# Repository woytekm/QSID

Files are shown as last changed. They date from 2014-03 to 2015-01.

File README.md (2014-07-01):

Q-SID: a 4-voice polyphonic MIDI synth based on four SID 8580 chips 

Features:

 Hardware/OS: 

 Q-SID will have a modular construction: every functional block of the device will have it's own PCB:
  - CPU board - Raspberry Pi, or other SoC board with two I2C busses, UART, at least 16 GPIO's, USB and ethernet
  - four voice boards, each with one 8580 SID chip
  - MIDI interface board
  - DSP/mixer board 
  - front controls board with rotary encoders and buttons for sound parameters control 
  - front display board 
  - I2C voltage level converter for voice boards
  - power supply with +9V, +5V switched for CPU, +5V linear for voice boards, +3.3V

 Q-SID will have an operating system in form of single multithreaded process of Linux OS, running on custom Raspbian image scaled down to
 stripped Linux kernel, Q-SID OS process, and prefferably nothing more (to spare CPU cycles and other resources).

 Synthetizer features:

  - 4 SID engines with full SID features
  - polyphonic mode with 4 voice polyphony
  - performance mode with keyboard/voice/patch split 
  - arpeggiator (not sure about exact parameters yet)
  - 2 software LFO's modulating filter cutoff/resonance, PWM, oscillator detune, and other parameters
  - onboard sound effects via internal DSP
  - MIDI in/out with programmable MIDI channel
  - embedded .sid chiptune player

====

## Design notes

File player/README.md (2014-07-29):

This directory contains complete, patched sources of sidplay and libsidplay2.
HardSID builder code was modified to use QSID voice board instead of HardSID card. 
Use: --hardsid --addr <board address> to play .sid song on a QSID voice board.

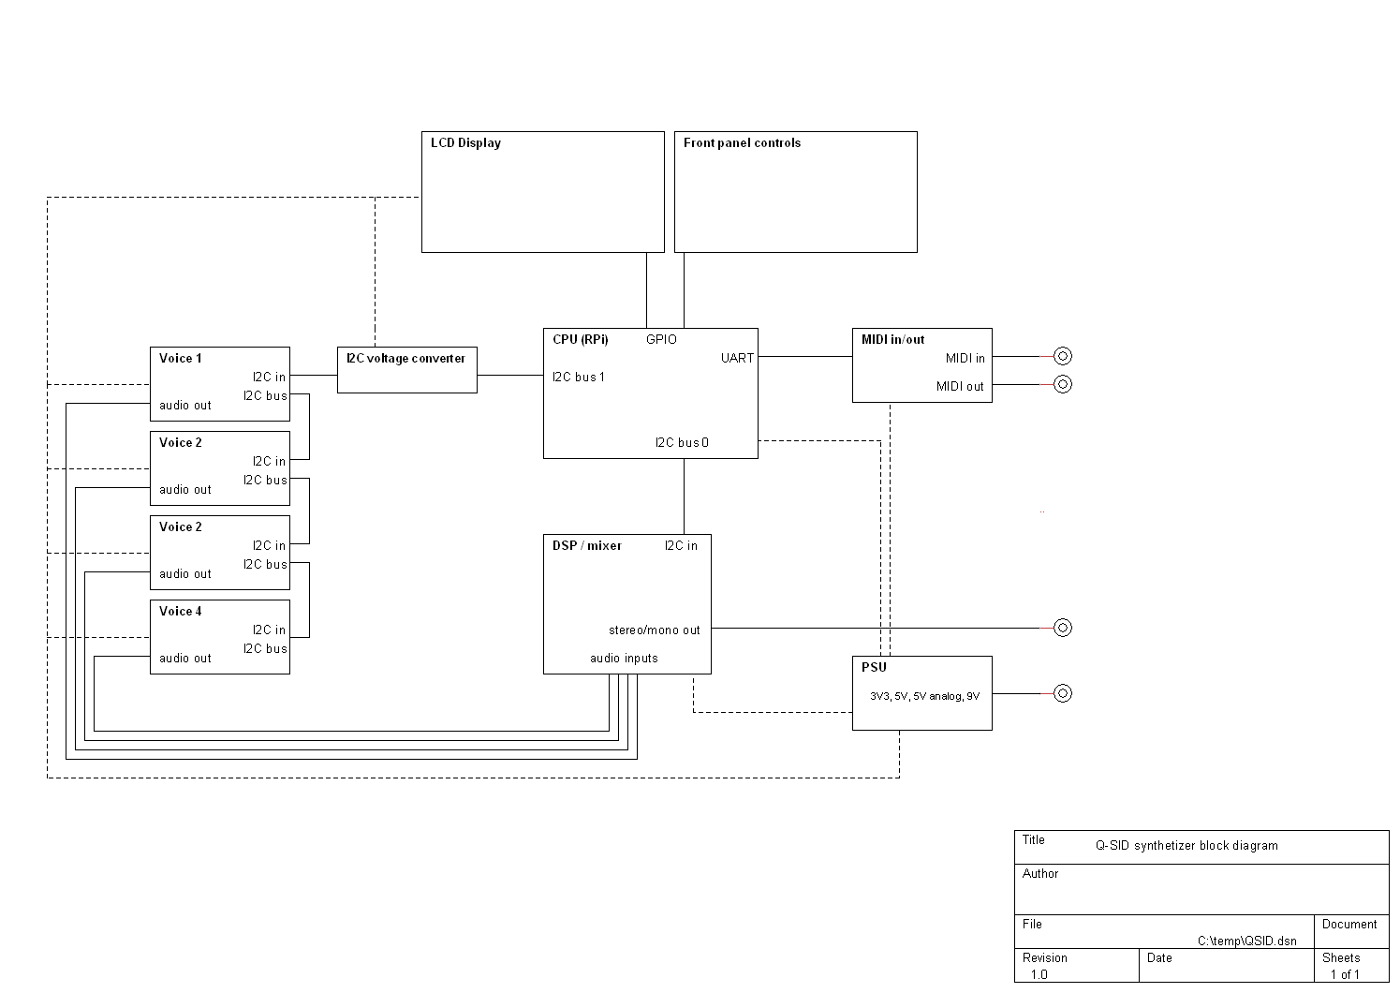
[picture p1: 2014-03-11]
hardware/Q-SID_block_diagram.png

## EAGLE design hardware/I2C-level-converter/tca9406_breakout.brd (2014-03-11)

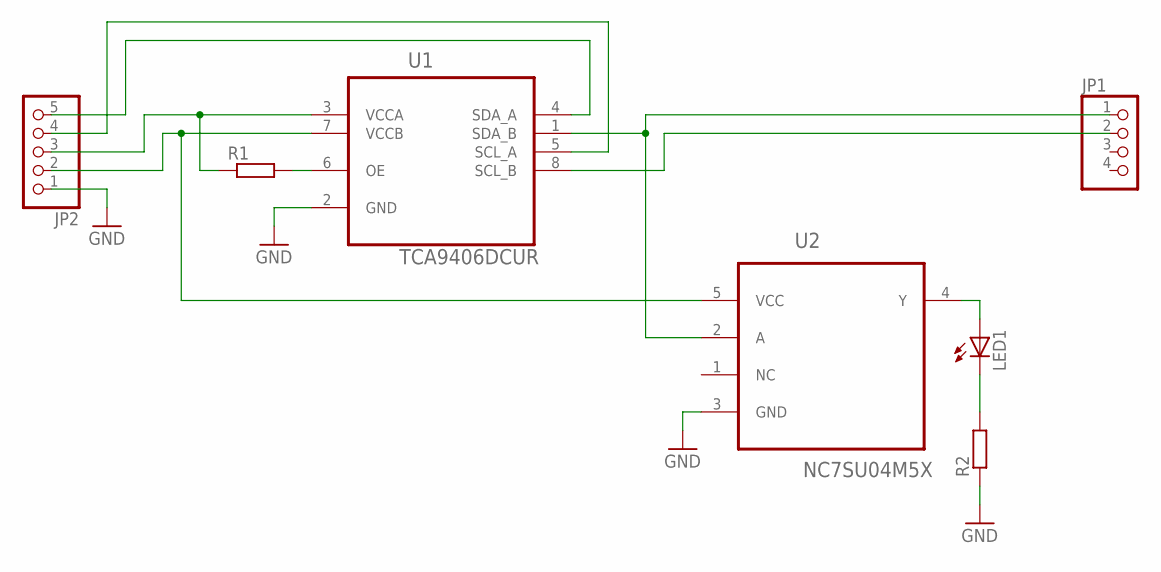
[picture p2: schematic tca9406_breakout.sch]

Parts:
JP1: PINHD-1X4; 1X04
JP2: PINHD-1X5; 1X05
LED1: LEDSML1206; SML1206
R1, R2: R-EU_M1406; M1406
U1: TCA9406DCUR; SOP50P310X90-8N
U2: NC7SU04M5X; SOT95P280X145-5N

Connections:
GND: JP2.1, R2.1, U1.2 (GND), U2.3 (GND)
unnamed: JP1.2, U1.8 (SCL_B)
unnamed: JP1.1, U1.1 (SDA_B), U2.2 (A)
unnamed: JP2.5, U1.4 (SDA_A)
unnamed: JP2.4, U1.5 (SCL_A)
unnamed: JP2.3, R1.1, U1.3 (VCCA)
unnamed: JP2.2, U1.7 (VCCB), U2.5 (VCC)
unnamed: LED1.A, U2.4 (Y)
unnamed: R1.2, U1.6 (OE)
unnamed: LED1.C, R2.2

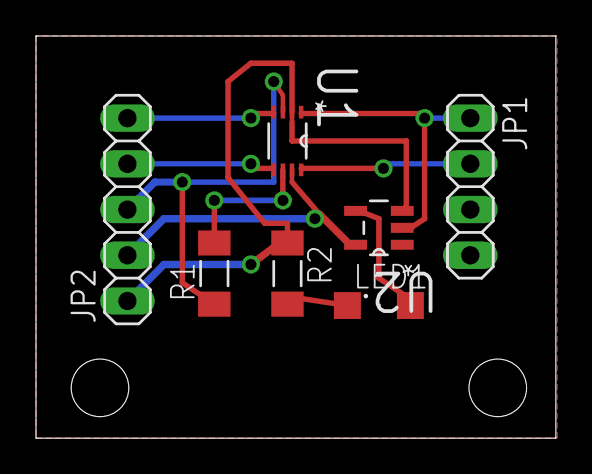
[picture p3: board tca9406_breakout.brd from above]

Board: 2 copper layers, 28.9 x 22.3 mm, 7 parts (0 on the bottom side), 10 nets.

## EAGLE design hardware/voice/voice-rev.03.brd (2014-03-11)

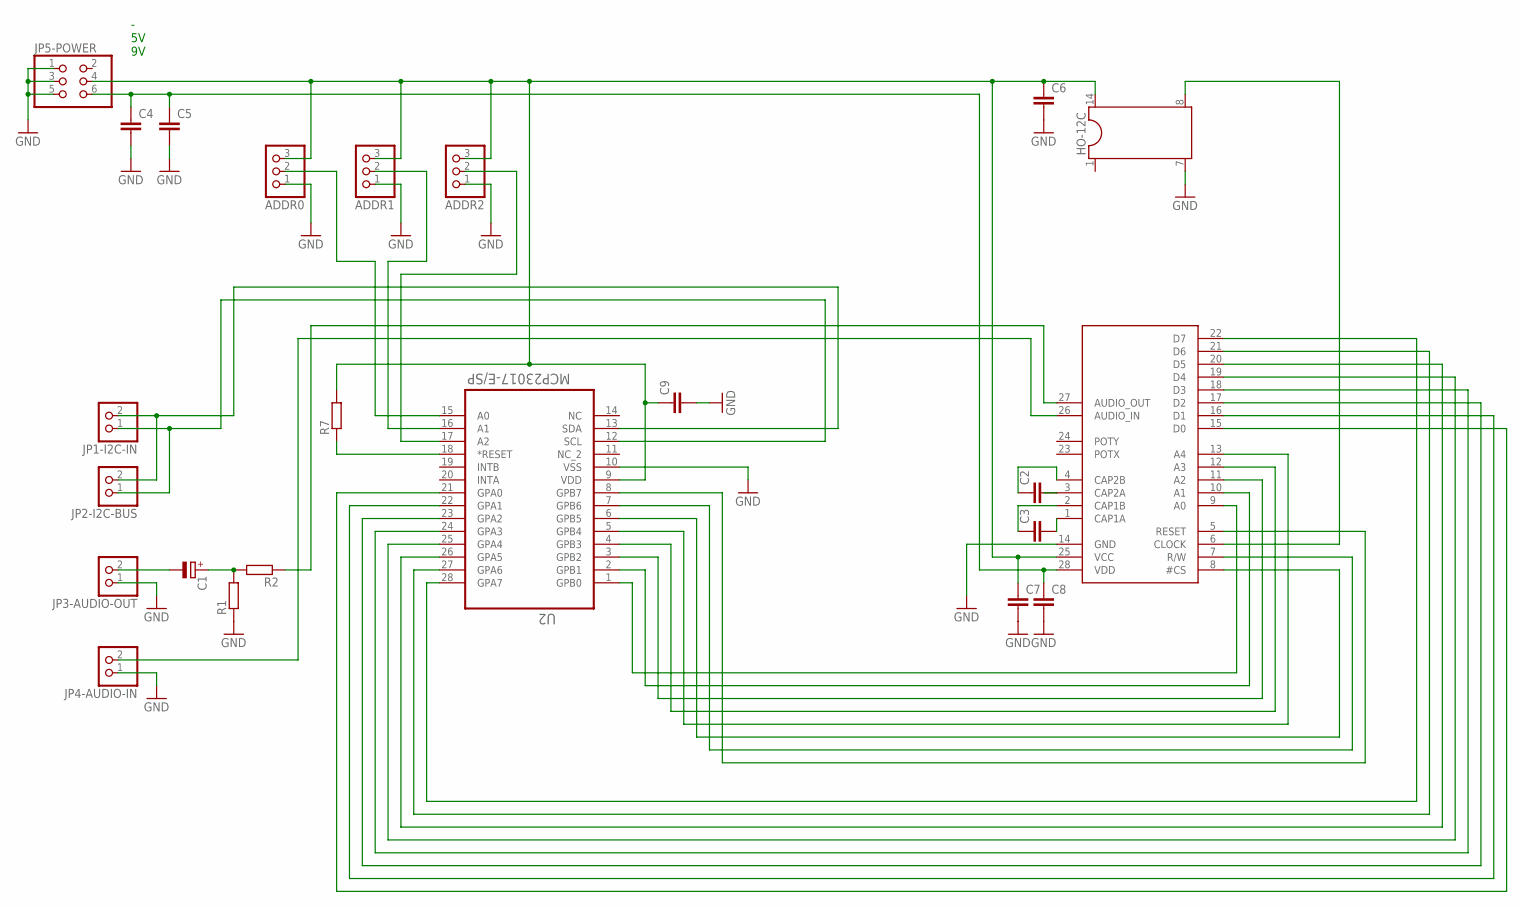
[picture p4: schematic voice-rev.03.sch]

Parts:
ADDR0, ADDR1, ADDR2: PINHD-1X3; 1X03
C1: CPOL-EUE2.5-5; E2,5-5
C2, C3: C5/2.5; C5B2.5
C4, C5, C6, C7, C8, C9: C-EU050-024X044; C050-024X044
HO-12C: DIL14/4
JP1-I2C-IN, JP2-I2C-BUS, JP3-AUDIO-OUT, JP4-AUDIO-IN: PINHD-1X2; 1X02
JP5-POWER: PINHD-2X3; 2X03
R1, R2, R7: R-EU_0207/5V; 0207/5V
U2: MCP23017-E/SP; DIP254P762X406-28P
U$1: 6581; DIL28-6

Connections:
GND: ADDR0.1, ADDR1.1, ADDR2.1, C4.2, C5.2, C6.2, C7.2, C8.2, C9.2, HO-12C.7 (8), JP3-AUDIO-OUT.1, JP4-AUDIO-IN.1, JP5-POWER.1, JP5-POWER.3, JP5-POWER.5, R1.1, U2.10 (VSS), U$1.14 (GND)
unnamed: U2.1 (GPB0), U$1.9 (A0)
unnamed: U2.2 (GPB1), U$1.10 (A1)
unnamed: U2.3 (GPB2), U$1.11 (A2)
unnamed: U2.4 (GPB3), U$1.12 (A3)
unnamed: U2.5 (GPB4), U$1.13 (A4)
unnamed: U2.6 (GPB5), U$1.8 (#CS)
unnamed: U2.7 (GPB6), U$1.7 (R/W)
unnamed: U2.8 (GPB7), U$1.5 (RESET)
unnamed: U2.28 (GPA7), U$1.22 (D7)
unnamed: U2.27 (GPA6), U$1.21 (D6)
unnamed: U2.26 (GPA5), U$1.20 (D5)
unnamed: U2.25 (GPA4), U$1.19 (D4)
unnamed: U2.24 (GPA3), U$1.18 (D3)
unnamed: U2.23 (GPA2), U$1.17 (D2)
unnamed: U2.22 (GPA1), U$1.16 (D1)
unnamed: U2.21 (GPA0), U$1.15 (D0)
unnamed: HO-12C.8 (9), U$1.6 (CLOCK)
unnamed: C1.+, R1.2, R2.2
unnamed: C4.1, C5.1, C8.1, JP5-POWER.6, U$1.28 (VDD)
unnamed: R2.1, U$1.27 (AUDIO_OUT)
unnamed: JP4-AUDIO-IN.2, U$1.26 (AUDIO_IN)
unnamed: JP1-I2C-IN.2, JP2-I2C-BUS.2, U2.13 (SDA)
unnamed: JP1-I2C-IN.1, JP2-I2C-BUS.1, U2.12 (SCL)
unnamed: C1.-, JP3-AUDIO-OUT.2
unnamed: C3.2, U$1.1 (CAP1A)
unnamed: C3.1, U$1.2 (CAP1B)
unnamed: C2.2, U$1.3 (CAP2A)
unnamed: C2.1, U$1.4 (CAP2B)
unnamed: ADDR0.2, U2.15 (A0)
unnamed: ADDR1.2, U2.16 (A1)
unnamed: ADDR2.2, U2.17 (A2)
unnamed: R7.1, U2.18 (*RESET)
unnamed: ADDR0.3, ADDR1.3, ADDR2.3, C6.1, C7.1, C9.1, HO-12C.14 (16), JP5-POWER.4, R7.2, U2.9 (VDD), U$1.25 (VCC)

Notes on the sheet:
- 5V 9V

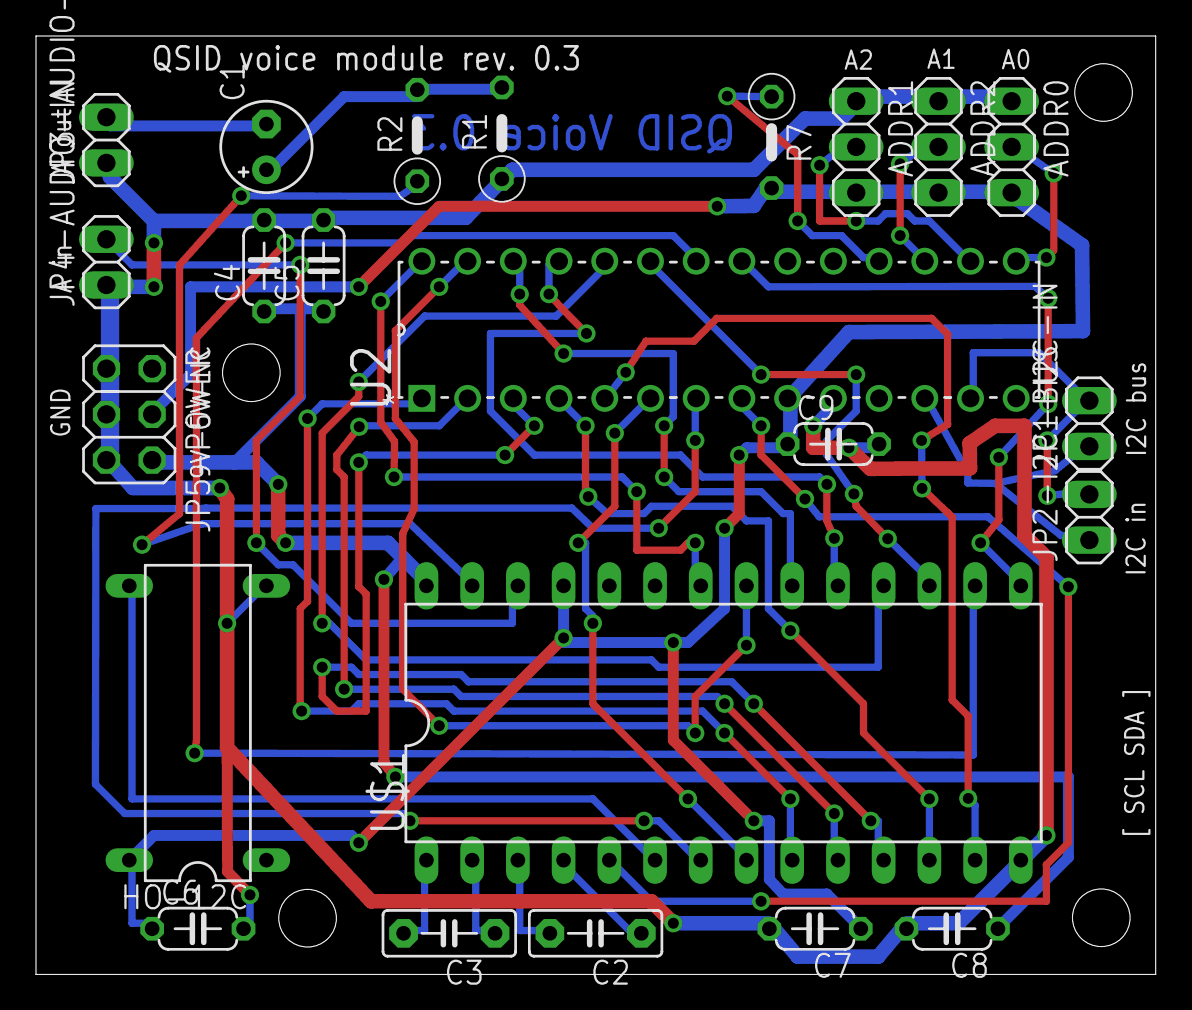
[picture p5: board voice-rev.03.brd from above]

Board: 2 copper layers, 62.2 x 52.1 mm, 23 parts (0 on the bottom side), 34 nets.

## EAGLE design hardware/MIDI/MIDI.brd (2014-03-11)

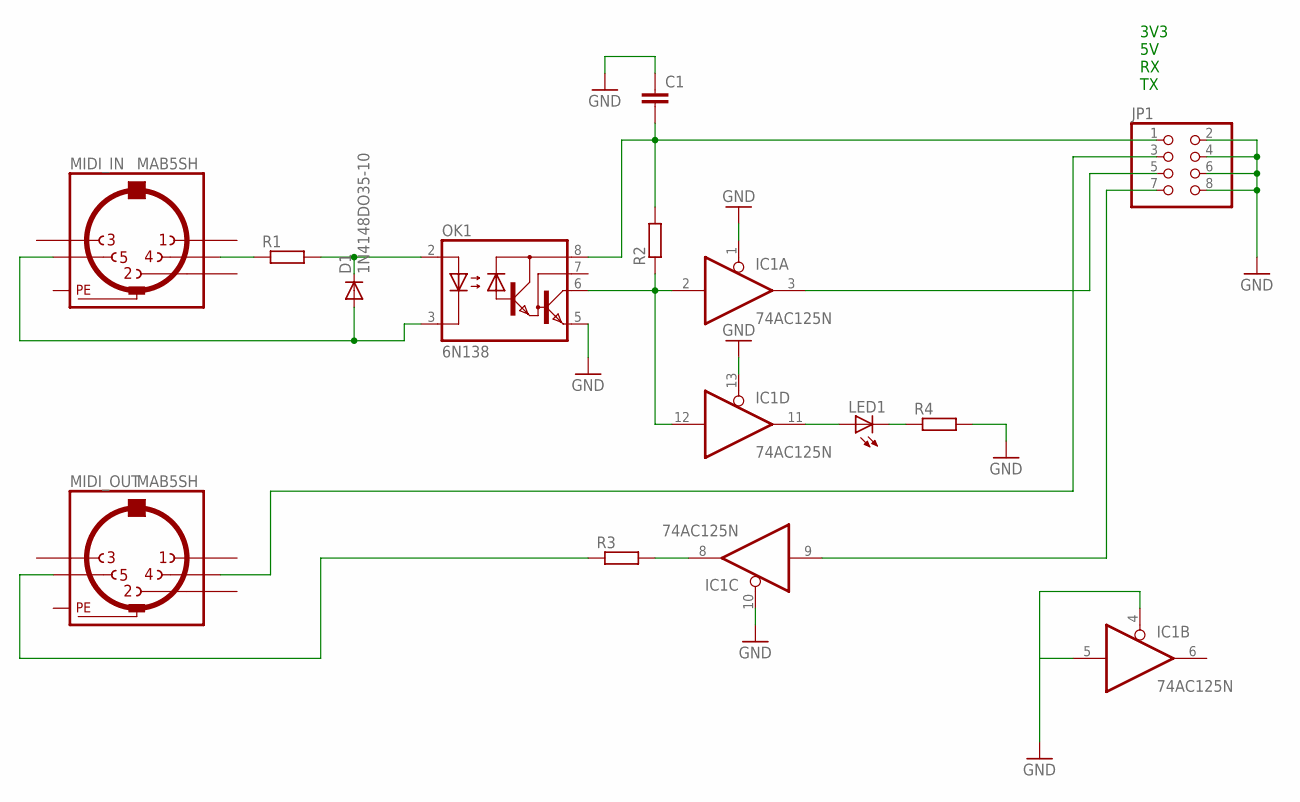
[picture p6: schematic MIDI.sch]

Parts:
C1: C-EU050-024X044; C050-024X044
D1: 1N4148DO35-10; DO35-10
IC1: 74AC125N; DIL14
JP1: PINHD-2X4; 2X04
LED1: LED3MM
MIDI_IN: MAB5SH
MIDI_OUT: MAB5SH
OK1: 6N138; DIL08
R1, R2, R3, R4: R-EU_0207/5V; 0207/5V

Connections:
GND: C1.1, IC1.1 (OE), IC1.4 (OE), IC1.5 (I), IC1.7 (GND), IC1.10 (OE), IC1.13 (OE), JP1.2, JP1.4, JP1.6, JP1.8, MIDI_IN.PE, MIDI_IN.PE@ (PE), MIDI_OUT.PE, MIDI_OUT.PE@ (PE), OK1.5 (GND), R4.2
unnamed: MIDI_IN.4, R1.1
unnamed: D1.C, OK1.2 (A), R1.2
unnamed: D1.A, MIDI_IN.5, OK1.3 (C)
unnamed: IC1.8 (O), R3.2
unnamed: IC1.2 (I), IC1.12 (I), OK1.6 (VO), R2.1
unnamed: IC1.3 (O), JP1.5
unnamed: MIDI_OUT.5, R3.1
unnamed: JP1.3, MIDI_OUT.4
unnamed: IC1.9 (I), JP1.7
unnamed: IC1.11 (O), LED1.A
unnamed: LED1.K (C), R4.1
VCC: C1.2, IC1.14 (VCC), JP1.1, OK1.8 (VCC), R2.2

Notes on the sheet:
3V3 5V RX TX

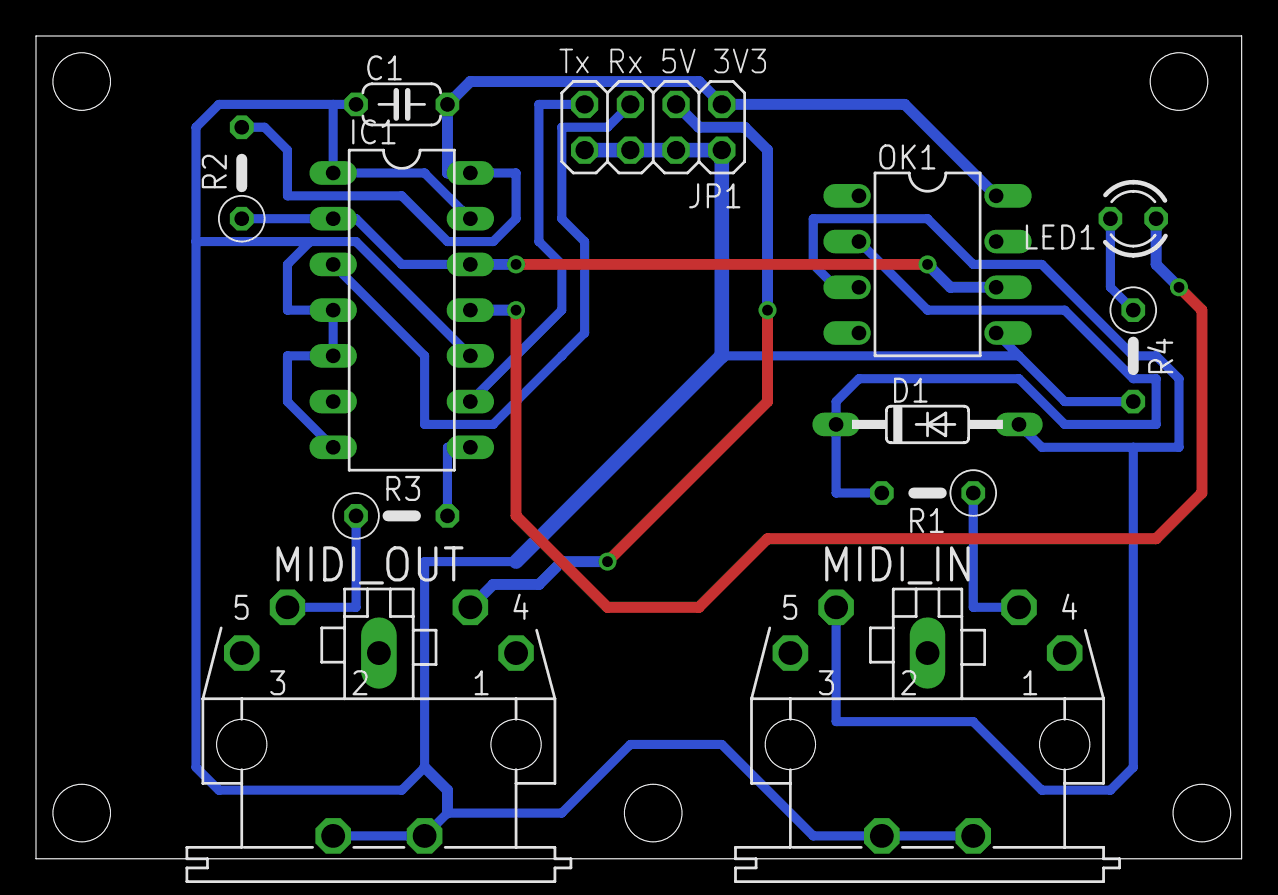
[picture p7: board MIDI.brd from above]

Board: 2 copper layers, 67.0 x 45.7 mm, 12 parts (0 on the bottom side), 13 nets.

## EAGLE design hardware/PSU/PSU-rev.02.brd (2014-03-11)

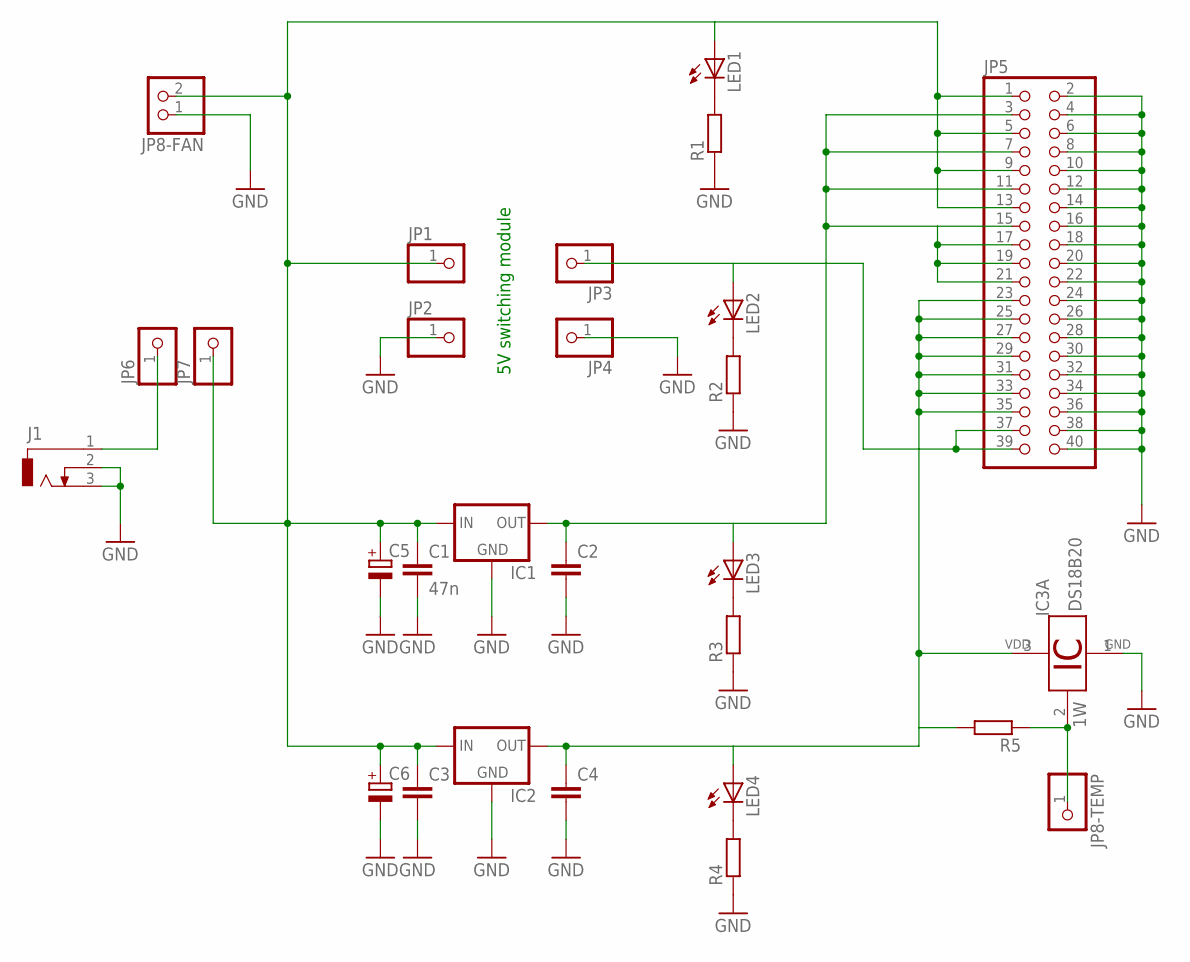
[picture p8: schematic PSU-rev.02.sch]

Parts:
C1: 47n; C050-024X044
C2, C3, C4: C-EU050-024X044; C050-024X044
C5, C6: CPOL-EUE3.5-8; E3,5-8
IC1, IC2: 78XXL
IC3: DS18B20; TO92-
J1: DCJ0303
JP1, JP2, JP3, JP4, JP6, JP7, JP8-TEMP: PINHD-1X1; 1X01
JP5: PINHD-2X20; 2X20
JP8-FAN: PINHD-1X2; 1X02
LED1, LED2, LED3, LED4: LEDSML1206; SML1206
R1, R2, R3, R4, R5: R-EU_R1206; R1206

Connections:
GND: C1.2, C2.2, C3.2, C4.2, C5.-, C6.-, IC1.GND, IC2.GND, IC3.1 (GND), J1.2, J1.3, JP2.1, JP4.1, JP5.2, JP5.4, JP5.6, JP5.8, JP5.10, JP5.12, JP5.14, JP5.16, JP5.18, JP5.20, JP5.22, JP5.24, JP5.26, JP5.28, JP5.30, JP5.32, JP5.34, JP5.36, JP5.38, JP5.40, JP8-FAN.1, R1.1, R2.1, R3.1, R4.1
unnamed: C1.1, C3.1, C5.+, C6.+, IC1.IN, IC2.IN, JP1.1, JP5.1, JP5.5, JP5.9, JP5.13, JP7.1, JP8-FAN.2, LED1.A
unnamed: C2.1, IC1.OUT, JP5.3, JP5.7, JP5.11, JP5.15, JP5.17, JP5.19, JP5.21, LED3.A
unnamed: C4.1, IC2.OUT, IC3.3 (VDD), JP5.23, JP5.25, JP5.27, JP5.29, JP5.31, JP5.33, JP5.35, LED4.A, R5.2
unnamed: JP3.1, JP5.37, JP5.39, LED2.A
unnamed: J1.1, JP6.1
unnamed: IC3.2 (1W), JP8-TEMP.1, R5.1
unnamed: LED1.C, R1.2
unnamed: LED2.C, R2.2
unnamed: LED3.C, R3.2
unnamed: LED4.C, R4.2

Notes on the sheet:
5V switching module

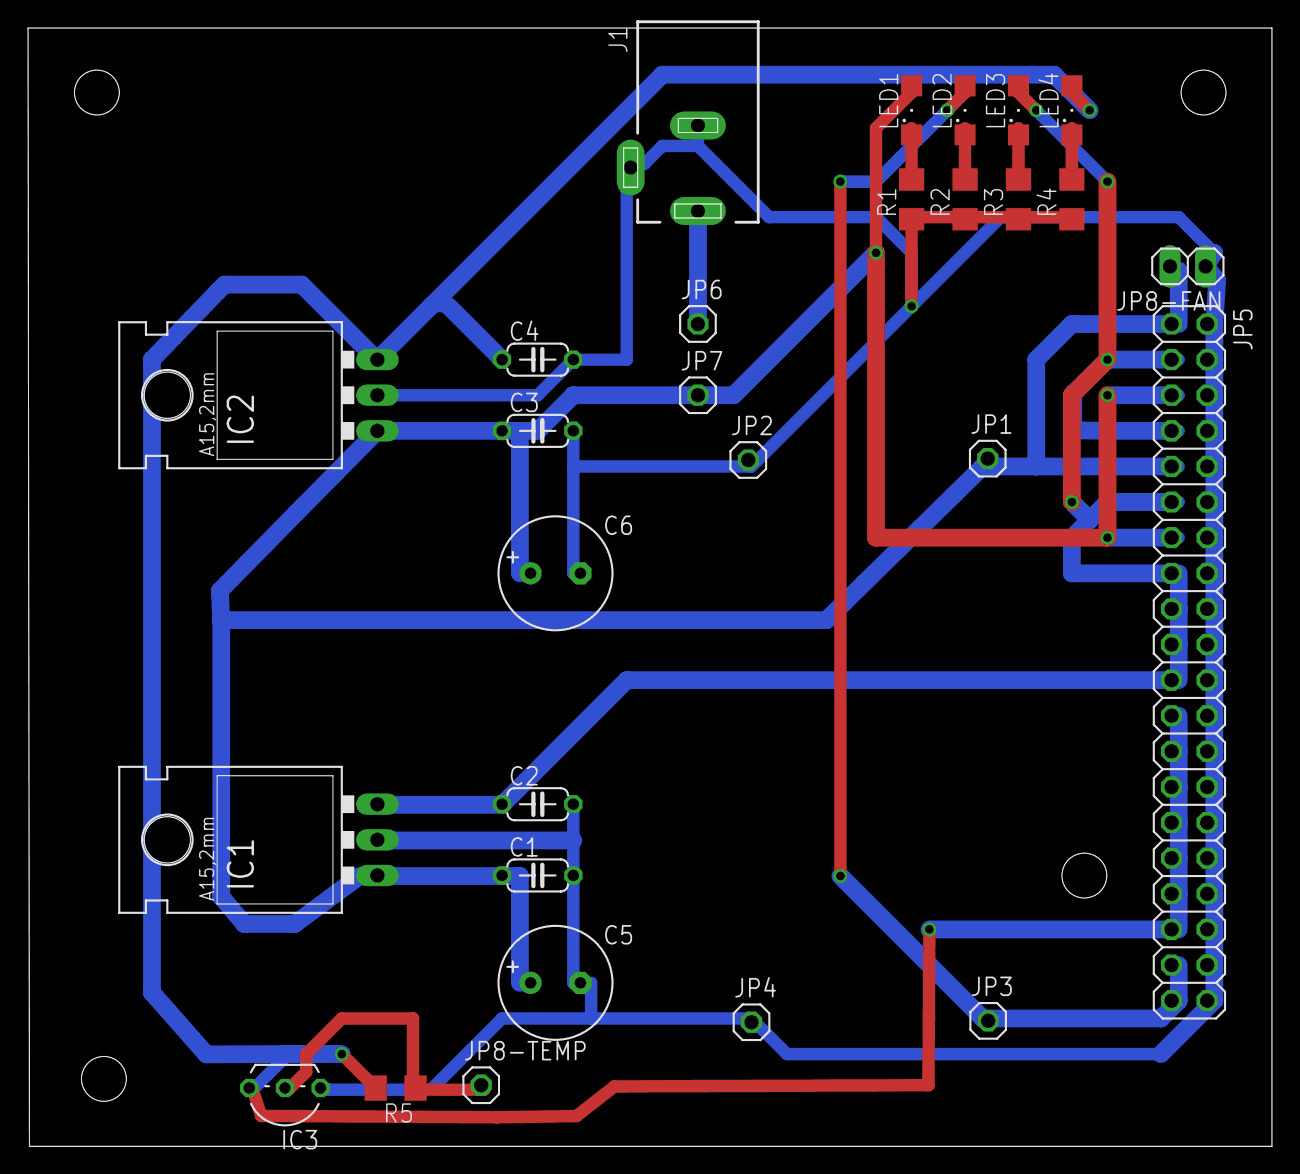
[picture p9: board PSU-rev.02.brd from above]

Board: 2 copper layers, 88.7 x 79.8 mm, 28 parts (0 on the bottom side), 11 nets.

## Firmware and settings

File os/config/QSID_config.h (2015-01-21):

/*

 Q-SID OS

 system configuration

*/

#define QSID_OS_VERSION_MAJOR 0
#define QSID_OS_VERSION_MINOR 1 

#ifdef I2C_BCM2835

#define I2C_VOICE_BUS 1
#define I2C_AUX_BUS 0
#define QSID_I2C_CLOCK 800000

#else

#define I2C_VOICE_BUS "/dev/i2c-1"
#define I2C_AUX_BUS   "/dev/i2c-0"

#endif

#define QSID_DEFAULT_THREAD_STACK_SIZE 1024000

#define QSID_DEBUG 1
#define QSID_DEBUG_LEVEL 3

#define QSID_OS_SID_REMOTE_CONTROL_PORT 6677
#define QSID_OS_MIDI_UDP_PORT 6678

#define DISCARD_DUPLICATE_NOTES 1
#define USE_SILENCERS 1

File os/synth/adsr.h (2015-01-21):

/* flags indicating events */
 
sig_atomic_t G_V_ADSR_stop[9];

sig_atomic_t G_V_ADSR_release_start[9];

/* signal handler arrays */

void (*G_ADSR_release_SH[9])(int);
void (*G_ADSR_stop_SH[9])(int);

/* modulation steps & intervals */

static const uint16_t G_ADSR_attack_steps[16] = {5,10,20,25,25,25,25,25,25,25,25,25,50,50,50,50};
static const uint32_t G_ADSR_attack_intervals[16] = {400,800,800,960,1520,2240,2720,3200,4000,10000,20000,
                                                     32000,20000,60000,100000,160000};
static const uint16_t G_ADSR_attack_step_size[16] = {409,204,102,81,81,81,81,81,81,81,81,81,40,40,40,40};

#define ADSR_ATTACK_STEPS_0 5
#define ADSR_ATTACK_STEPS_1 10
#define ADSR_ATTACK_STEPS_2 20
#define ADSR_ATTACK_STEPS_3 25
#define ADSR_ATTACK_STEPS_4 25
#define ADSR_ATTACK_STEPS_5 25
#define ADSR_ATTACK_STEPS_6 25
#define ADSR_ATTACK_STEPS_7 25
#define ADSR_ATTACK_STEPS_8 25
#define ADSR_ATTACK_STEPS_9 25
#define ADSR_ATTACK_STEPS_10 25
#define ADSR_ATTACK_STEPS_11 25
#define ADSR_ATTACK_STEPS_12 50
#define ADSR_ATTACK_STEPS_13 50
#define ADSR_ATTACK_STEPS_14 50
#define ADSR_ATTACK_STEPS_15 50

#define ADSR_ATTACK_MOD_INTERVAL_0 400     /* 2ms */
#define ADSR_ATTACK_MOD_INTERVAL_1 800     /* 8ms */
#define ADSR_ATTACK_MOD_INTERVAL_2 800     /* 16ms */
#define ADSR_ATTACK_MOD_INTERVAL_3 960     /* 24ms */
#define ADSR_ATTACK_MOD_INTERVAL_4 1520    /* 38ms */
#define ADSR_ATTACK_MOD_INTERVAL_5 2240    /* 56ms */
#define ADSR_ATTACK_MOD_INTERVAL_6 2720    /* 68ms */
#define ADSR_ATTACK_MOD_INTERVAL_7 3200    /* 80ms */
#define ADSR_ATTACK_MOD_INTERVAL_8 4000    /* 100ms */
#define ADSR_ATTACK_MOD_INTERVAL_9 10000    /* 250ms */
#define ADSR_ATTACK_MOD_INTERVAL_10 20000   /* 500ms */
#define ADSR_ATTACK_MOD_INTERVAL_11 32000   /* 800ms */
#define ADSR_ATTACK_MOD_INTERVAL_12 20000   /* 1s    */
#define ADSR_ATTACK_MOD_INTERVAL_13 60000   /* 3s    */
#define ADSR_ATTACK_MOD_INTERVAL_14 100000   /* 5s    */
#define ADSR_ATTACK_MOD_INTERVAL_15 160000   /* 8s    */

#define ADSR_ATTACK_STEP_SIZE_0 409
#define ADSR_ATTACK_STEP_SIZE_1 204
#define ADSR_ATTACK_STEP_SIZE_2 102
#define ADSR_ATTACK_STEP_SIZE_3 81
#define ADSR_ATTACK_STEP_SIZE_4 81
#define ADSR_ATTACK_STEP_SIZE_5 81
#define ADSR_ATTACK_STEP_SIZE_6 81
#define ADSR_ATTACK_STEP_SIZE_7 81
#define ADSR_ATTACK_STEP_SIZE_8 81
#define ADSR_ATTACK_STEP_SIZE_9 81
#define ADSR_ATTACK_STEP_SIZE_10 81
#define ADSR_ATTACK_STEP_SIZE_11 81
#define ADSR_ATTACK_STEP_SIZE_12 40
#define ADSR_ATTACK_STEP_SIZE_13 40
#define ADSR_ATTACK_STEP_SIZE_14 40
#define ADSR_ATTACK_STEP_SIZE_15 40


#define ADSR_DECAY_STEPS_1 3
#define ADSR_DECAY_STEPS_2 7
#define ADSR_DECAY_STEPS_3 15
#define ADSR_DECAY_STEPS_4 20
#define ADSR_DECAY_STEPS_5 30
 
#define ADSR_RELEASE_STEPS_1 3
#define ADSR_RELEASE_STEPS_2 7
#define ADSR_RELEASE_STEPS_3 15
#define ADSR_RELEASE_STEPS_4 20
#define ADSR_RELEASE_STEPS_5 30
 

/* prototypes */

void SYNTH_filter_ADSR(void *arg);
void SYNTH_init_ADSR_event_handlers(void);
void SYNTH_init_ADSR_arrays(void);

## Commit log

2014-07-29 added .sid player code (complete sidplay2 sources modified to use QSID voice board instead of HardSID card)
2014-08-31 added cmdline option allowing to specify Q-SID board address
2014-09-16 added a lot of new stuff: basic polyphony code, midi-in thread, SID writer thread, started SID control code
2014-11-18 added alternative (faster) method of I2C access (BCM2835 library - local, patched copy)
2014-11-29 rewrote sysex encoder/decoder
2014-12-30 added oscillator silencer feature
    [init.c]
2015-01-03 bugfixes and minor improvements
    [QSID_config.h, detect.c]
2015-01-21 added patch management and started filter adsr generator
